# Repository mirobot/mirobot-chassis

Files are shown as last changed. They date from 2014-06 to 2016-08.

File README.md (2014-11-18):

Mirobot Chassis
===============

This repository contains the files that are needed to laser cut the chassis for Mirobot (http://mirobot.io). There are a few different files here:
 - mirobot_chassis_design.pdf - this is the main working file for Mirobot, but can't be used for laser cutting. It can be edited in Illustrator
 - mirobot_chassis_lasercut.pdf - these files are the laser-cuttable outlines laid out for cutting as pdf. SVG and DXF are available in the [releases](https://github.com/bjpirt/mirobot-chassis/releases)

These designs are currently designed to be cut from 3mm MDF board.

This repository is in a state of development, see the [releases](https://github.com/bjpirt/mirobot-chassis/releases) for known good snapshots. No guarantees are made - laser cut at your own risk!

Licensing
=========

Mirobot is an open hardware project licensed under the TAPR Open Hardware License (http://www.tapr.org/ohl.html). The name Mirobot may not be used commercially without permission. If you have any questions please get in touch (info@mirobot.io)

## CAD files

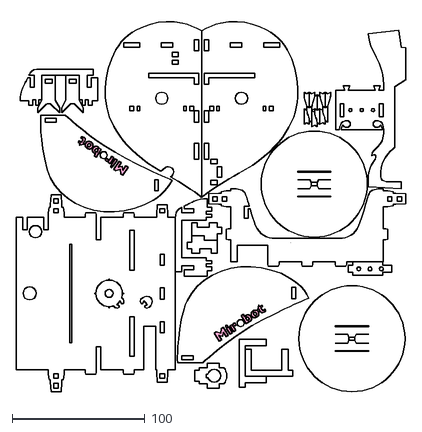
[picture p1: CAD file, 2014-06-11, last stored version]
mirobot_chassis_lasercut.dxf
293.5 x 283.4

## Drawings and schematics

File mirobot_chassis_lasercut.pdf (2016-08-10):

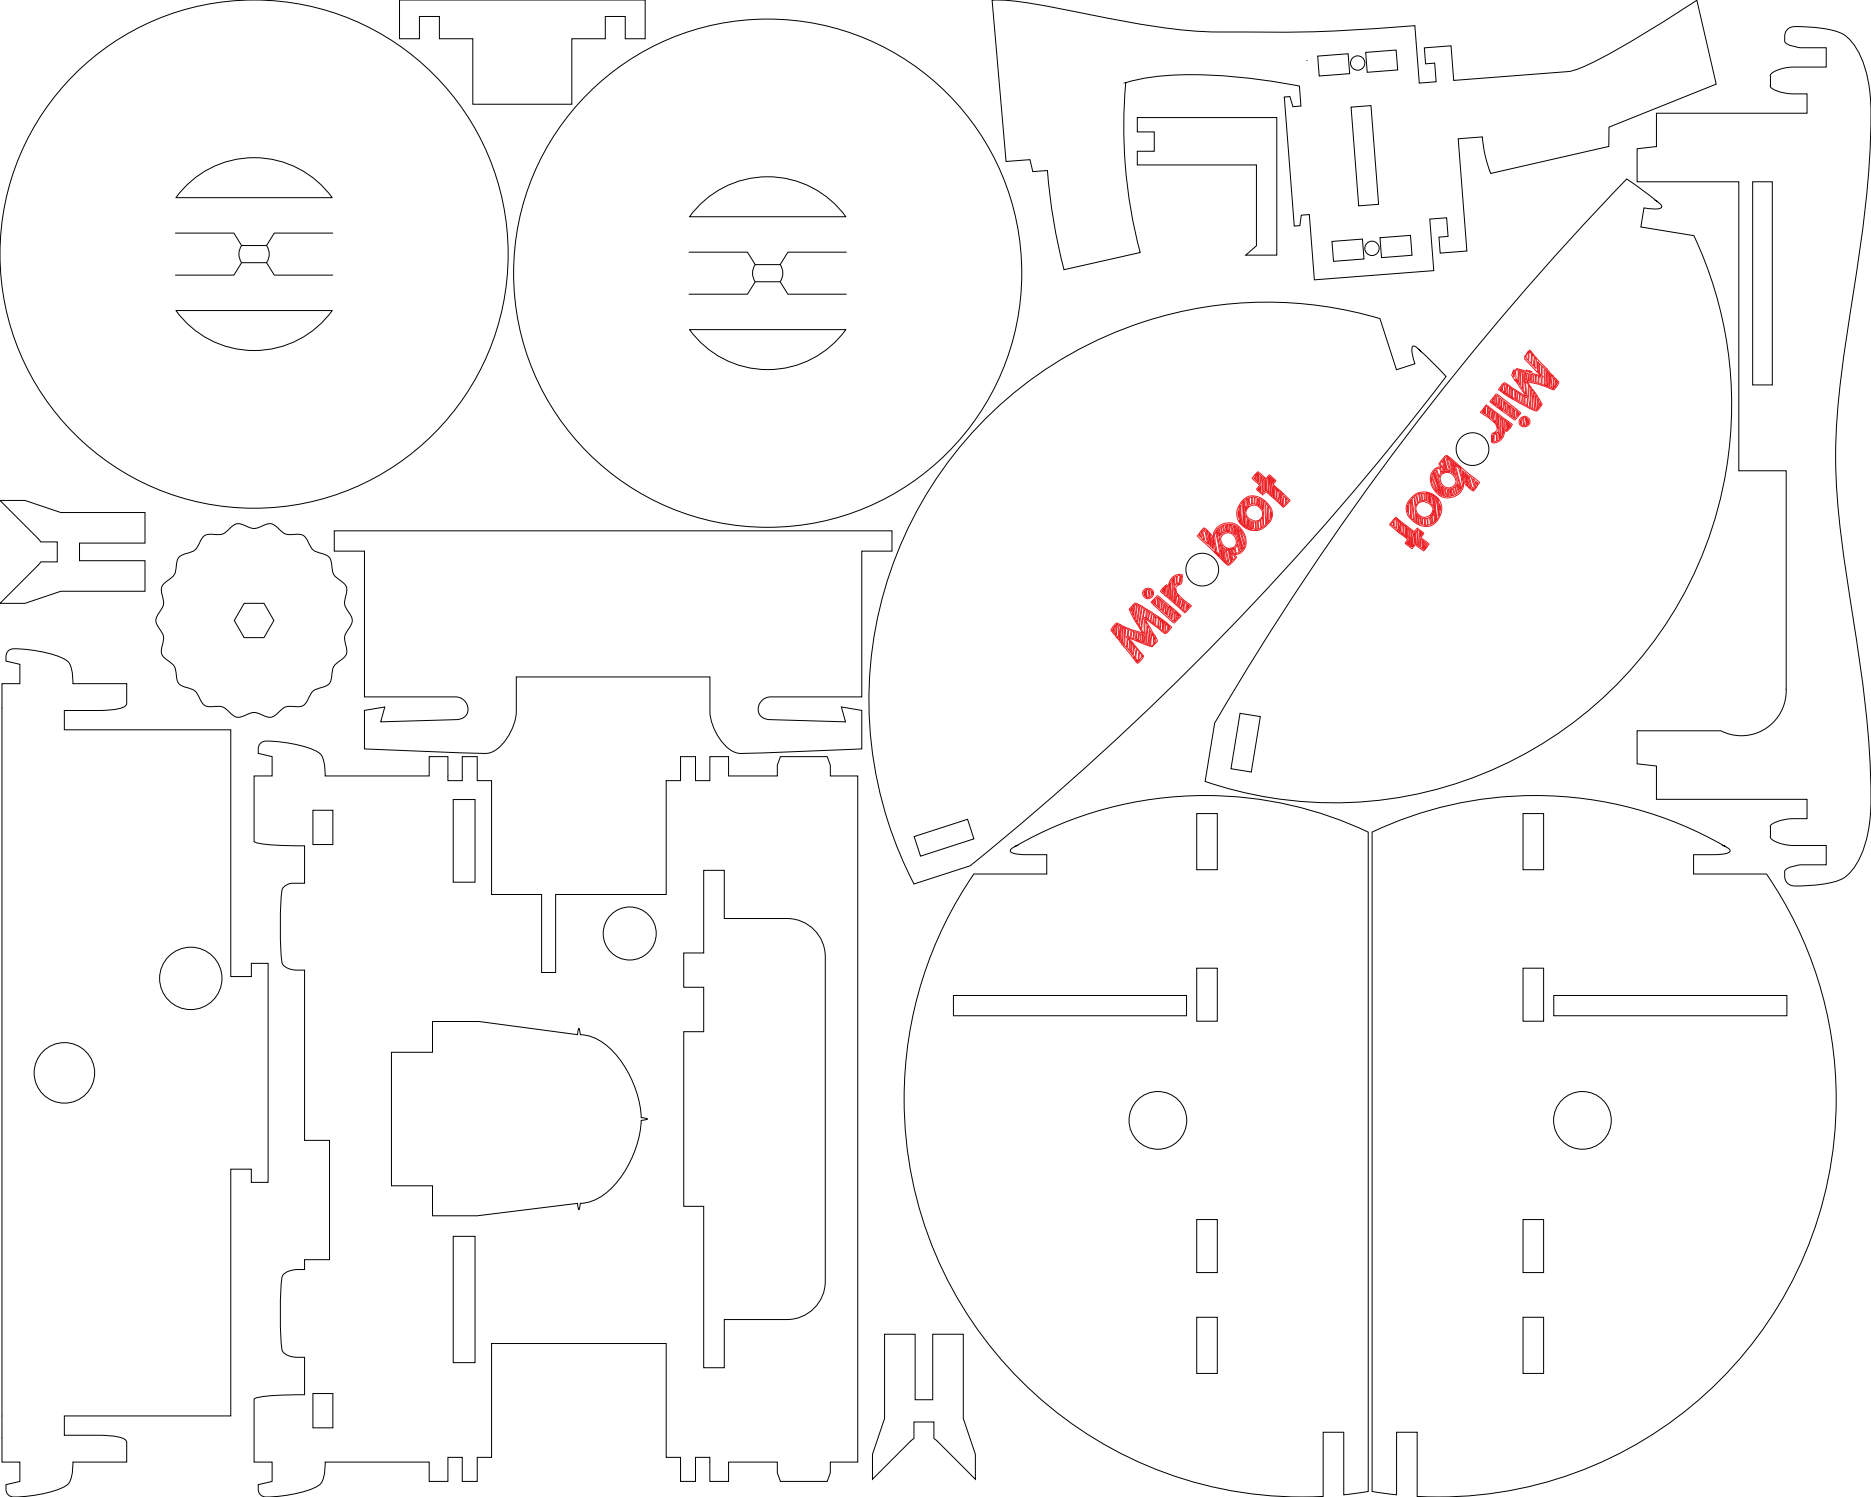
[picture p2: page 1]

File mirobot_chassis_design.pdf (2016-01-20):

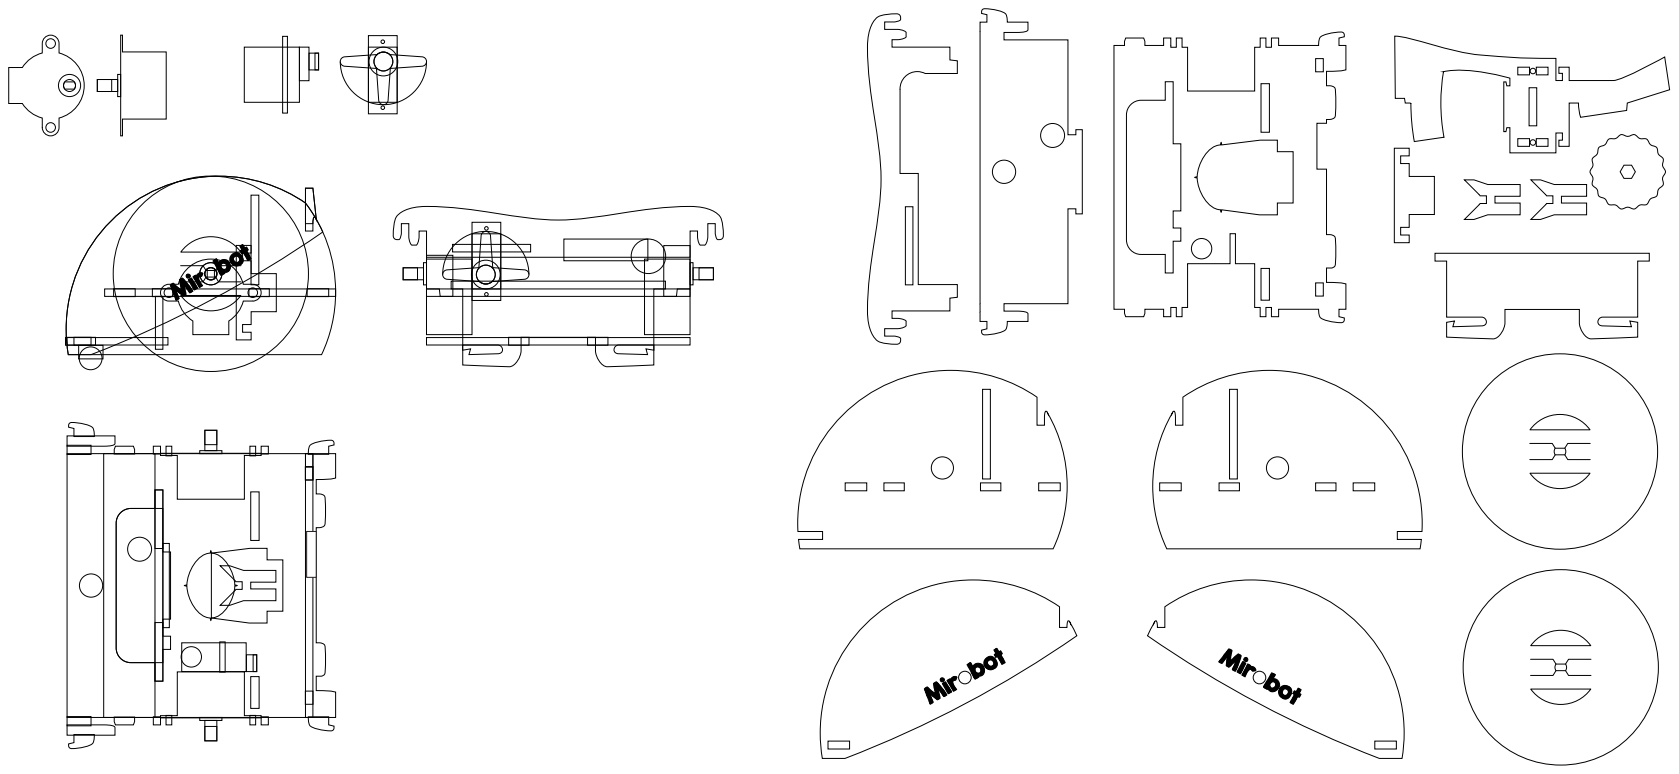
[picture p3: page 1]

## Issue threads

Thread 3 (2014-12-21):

Getting pen to drop effectively

ajfisher, 2014-12-21:
I've got my bot all working okay except for one thing which is the pen dropping back down into place. It feels like the pen arm is maybe a bit too fitted to the site pieces that it sits within.

What's the general view of getting it to drop down when the servo moves to the down position?

fly72t, 2015-01-11:
Same for me. The servo was able to push the pen up but it sticks there. I disassembled half of the robot and tweaked the arm as well as the chassis. It's better but not perfect. Maybe some more exercise will help. My son is practicing geometrical figure and letters....
@Ben, with the robots that I had it was always the right side (servo side). A bid wider slot would seriously help.

ajfisher, 2015-01-11:
Yeah - I had a play with sanding it back over the weekend - looks like mine
is sticking on not just the sides but the bottom point too so I need to
pull it apart and try again. I'd reckon making the slots for it like 1mm
wider in each case would sort it out...

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

bjpirt, 2015-02-02:
I've noted this for the next version so am closing this now.

Closed 2015-02-02.

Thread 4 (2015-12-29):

Chassis v2 svg wrong size info when opened in inkscape

mcarne, 2015-12-29:
size of the canvas & sheet should be increased to 300 by 240 mm to reflect correct size when opened in inkscape.

bjpirt, 2016-01-04:
I see what you mean - it looks like I forgot to scale the inkscape version before uploading it. I'll fix it now, thanks for letting me know

Closed 2016-01-04.

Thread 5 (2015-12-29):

Chassis v2 svg Mirobot logo increases file size and increases cutting time

mcarne, 2015-12-29:
I suggest to change the logo type on the Chassis. The current logo increases the file size 20 times from 25k to 500k.
Furthermore the current logo takes long to print thus increases the cost of cutting the parts considerably. Should be changed to a logo / brand name that is faster to print.

bjpirt, 2016-01-04:
How did you etch this part? It would take a long time if you cut each piece of the logo as an outline, but if you etched it it would take the same time as any other logo since it just scans back and forth. As this is the same as the production Mirobot I'm leaving it as-is, but you're welcome to change it if you feel the urge

Closed 2016-01-04.

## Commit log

2014-01-22 Initail commit of Mirobot chassis design
    [mirobot_chassis_lasercut.dxf]
2014-03-25 Added antenna mount
2014-04-18 Added antenna mount to chassis
2014-04-18 Updated the wheel mounting mechanism
2014-04-18 Tweak some of the parts to make assembly a bit easier
2014-06-11 Using pdf as the main file format because it's more accessible
    [mirobot_chassis_lasercut.dxf]
2014-06-11 Update README and remove the release files
    [mirobot_chassis_lasercut.dxf]
2014-07-30 Tweak the antenna mount
2015-03-25 Re-work of the chassis design for v2
2015-10-06 Production version of the v2 chassis
2016-01-20 Minor update to fix an issue in the lasercut file
2016-08-10 Fix error in laser cut file where wheel was offset
